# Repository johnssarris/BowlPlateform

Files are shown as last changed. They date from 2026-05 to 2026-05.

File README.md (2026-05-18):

# Dog Bowl Platform

Parametric, 3D-printable elevated dog bowl stand. Redesigned from scratch in OpenSCAD with three engineering priorities:

- **100% printed** — zero hardware, no bolts, no rubber feet, no glue
- **Tool-free** — snap-fit joints assemble and disassemble by hand in under 2 minutes
- **Portable** — 10 parts stack flat; toss in a bag

---

## Part List

| Part | Count | Unique shapes | File |
|---|---|---|---|
| Corner post | 4× | 1 | `openscad/parts/corner_post.scad` |
| Horizontal rail | 4× | 1 | `openscad/parts/horizontal_rail.scad` |
| Bowl cradle | 1–2× | 1 | `openscad/parts/bowl_cradle.scad` |

**3 unique shapes, 10 total pieces** (down from 32 in the original design).

---

## Structural Improvements vs Original

| Property | Original | Redesign | Gain |
|---|---|---|---|
| Frame cross-section | 10×10 mm solid | 20×20×3 mm hollow tube | 4× section modulus |
| Slenderness ratio | 47.6 : 1 | 23.8 : 1 | 2× column stability |
| Joint type | Flush / adhesive | Cantilever snap-tab | Hand-releasable, no glue |
| Foot contact area | 100 mm² | 962 mm² (ø35 pad) | 9.6× anti-tip stability |
| Part count | 32 | 10 | 69% reduction |
| Hardware needed | Adhesive | None | 100% printable |

---

## Quick Start

### 1. Open the master file

```
openscad/dog_bowl_platform.scad
```

Press **F5** (preview) to see the assembled stand.

### 2. Configure for your dog

Edit these variables at the top of `dog_bowl_platform.scad`:

```scad
bowl_diameter  = 200;   // outer diameter of your dog's bowl (mm)
num_bowls      = 2;     // 1 or 2 bowls
stand_height   = 200;   // floor to cradle surface (mm)
                         // rule of thumb: withers height × 0.45
```

Common `bowl_diameter` values:

| Bowl size | Diameter |
|---|---|
| Small (cat/small dog) | 140 mm |
| Medium dog | 180 mm |
| Large dog | 200–230 mm |
| Giant breed | 250 mm |

Common `stand_height` values:

| Dog size | Height |
|---|---|
| Small (≤10 kg) | 100 mm |
| Medium (10–25 kg) | 150–175 mm |
| Large (25–45 kg) | 200–250 mm |
| Giant (>45 kg) | 275–350 mm |

### 3. Export STL files

Run each part file individually to export one STL at a time:

```bash
# Using OpenSCAD CLI
openscad -o corner_post.stl    openscad/parts/corner_post.scad
openscad -o horizontal_rail.stl openscad/parts/horizontal_rail.scad
openscad -o bowl_cradle.stl    openscad/parts/bowl_cradle.scad
```

Or open each file in OpenSCAD, press **F6** (render), then **File → Export → Export as STL**.

> **Note:** The part files use `use <../dog_bowl_platform.scad>` to inherit parameters. Set your sizes in the master file before exporting.

### 4. Print settings

| Setting | Recommendation |
|---|---|
| Layer height | 0.2 mm |
| Infill | 30% (corner posts), 20% (rails and cradle) |
| Perimeters | 3 |
| Material | PLA or PETG |
| Supports | **None required** on any part |

**Print orientations:**

- **Corner post** — print vertically (Z-up). The foot pad is at the bottom of the print.
- **Horizontal rail** — print lying flat (longest axis along X). Snap tabs are at each end.
- **Bowl cradle** — print flat on bed, bowl openings facing up.

### 5. Tune fit tolerance

Default `snap_clearance = 0.25` works for most well-calibrated FDM printers.

- Too tight (tabs won't insert): increase to `0.30`
- Too loose (tabs rattle): decrease to `0.20`

Adjust in the master file and re-export only the affected parts.

---

## Assembly (tool-free, ~90 seconds)

1. Place 4 corner posts upright at the corners of your intended footprint, L-shape facing inward.
2. Slide the front rail's snap tabs into the slots on the two front posts — you'll hear/feel a click.
3. Slide the back rail into the two back posts.
4. Slide the left rail and right rail into their respective slots.
5. Drop the bowl cradle onto the top of the rail frame — the hook tabs on the cradle bottom engage the rail faces by gravity.
6. Place dog bowls.

**Disassembly:** Lift cradle straight up → squeeze each rail's snap tab cantilever inward and slide out → lift posts.

---

## Exploded View

Set `explode = 40` in the master file and press F5 to see all parts separated for verification.

---

## File Structure

```
openscad/
├── dog_bowl_platform.scad   ← Master file: all parameters + assembly
├── lib/
│   ├── frame.scad           ← Hollow chamfered tube module
│   └── joints.scad          ← Snap-tab and snap-slot modules
└── parts/
    ├── corner_post.scad     ← L-shaped post with integrated foot
    ├── horizontal_rail.scad ← Rail with snap tabs on both ends
    └── bowl_cradle.scad     ← Bowl support with hook tabs
STL/                         ← Original 32-piece design (reference)
Dog Bowl Plateform 2.step    ← Original OnShape assembly (reference)
```

---

## Design Notes

### Why hollow tube instead of solid?

A 20×20 mm hollow tube (3 mm wall) has **4× the section modulus** of the original 10×10 mm solid profile while using roughly the same material volume. Section modulus governs bending stiffness — the frame deflects far less under dog-bump loads.

### Why snap-fit instead of bolts?

Bolts require tools and mean hardware that can be lost. A properly designed cantilever snap-tab (3 mm wall, 15 mm arm) provides adequate retention under typical meal-time loading and releases with finger pressure. The cradle is gravity-retained and lifts off freely.

### Why a square footprint?

Making all 4 rails identical (one unique part instead of two) reduces print time and simplifies assembly. The square base footprint is derived directly from `bowl_diameter + 2 × bowl_rim`, so it scales correctly for any bowl size.

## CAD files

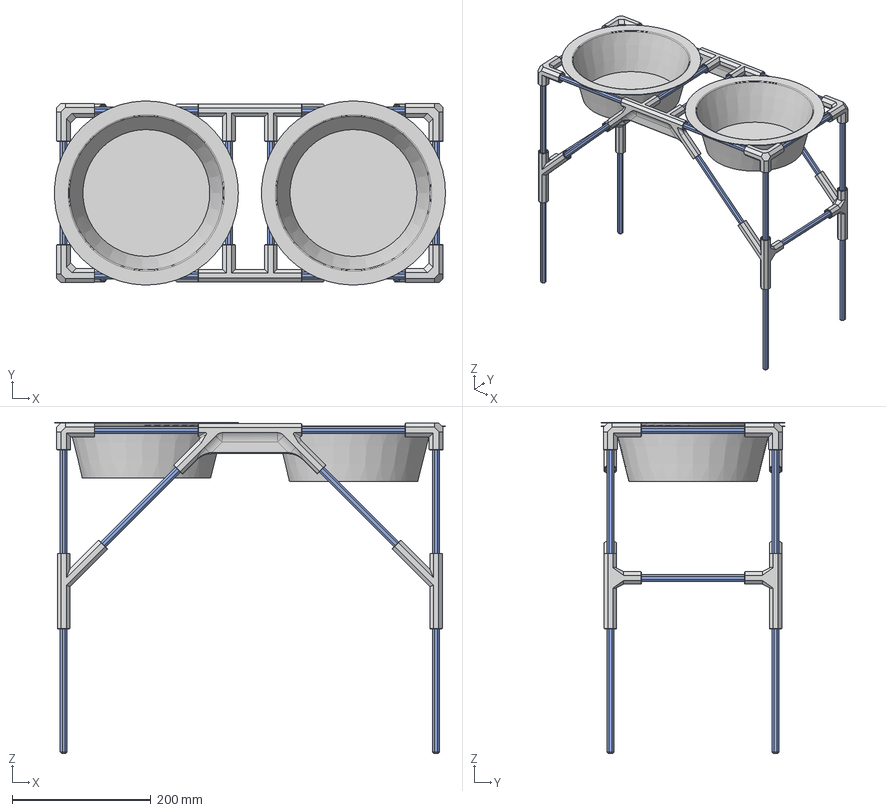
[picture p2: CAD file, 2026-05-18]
Dog Bowl Plateform.step
563.0 x 264.9 x 476.9 mm
Frame_Segment x 22
Center_Top x 2
Corner_Stabilizer_A x 2
Corner_Top x 4
Bowl x 2
Corner_Stabilizer_B x 2

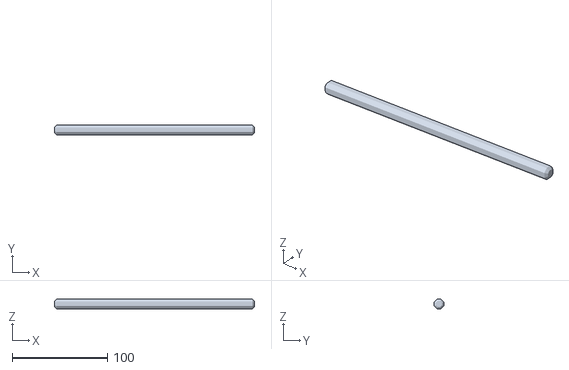
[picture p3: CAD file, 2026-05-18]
STL/Dog Bowl Plateform - Frame_Segment_20.stl
210.5 x 10.0 x 10.0

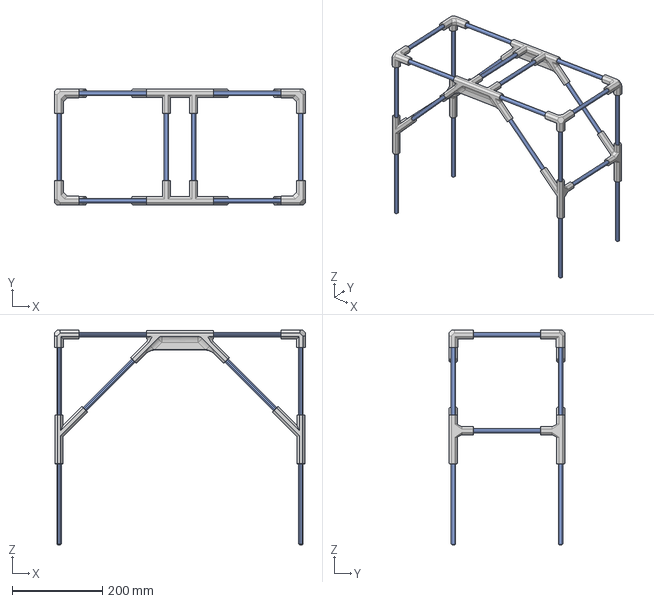
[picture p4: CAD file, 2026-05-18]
Dog Bowl Plateform 2.step
556.5 x 258.2 x 476.0 mm

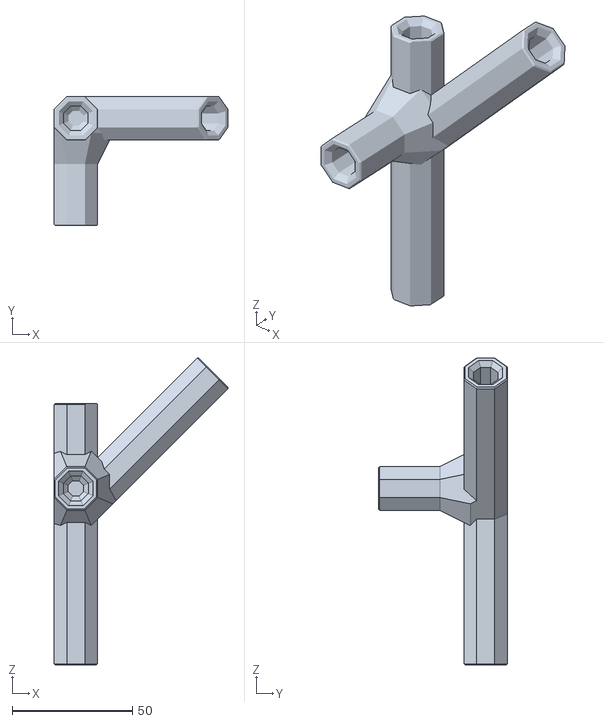
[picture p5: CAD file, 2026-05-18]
STL/Dog Bowl Plateform - Corner_Stabilizer_B_1.stl
72.3 x 53.6 x 127.5

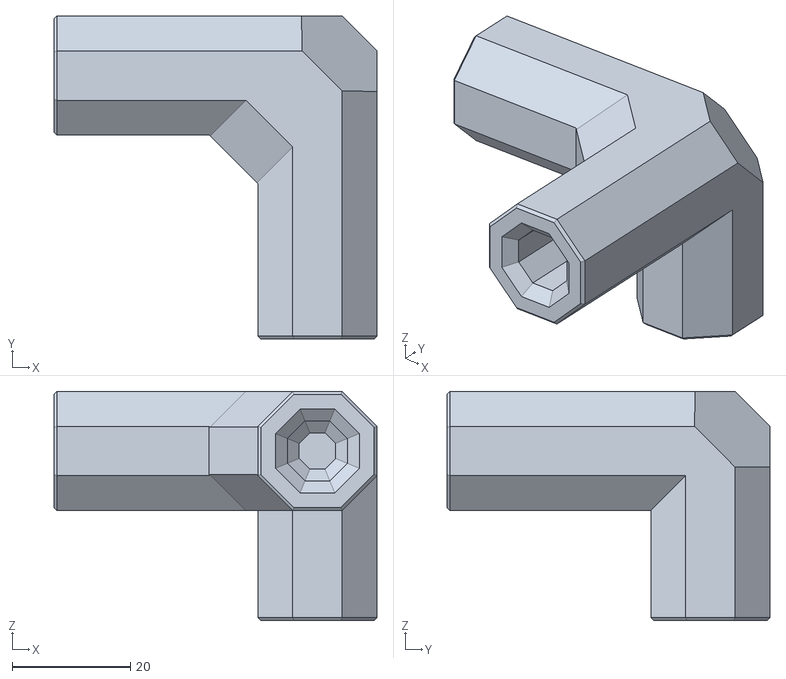
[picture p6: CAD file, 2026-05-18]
STL/Dog Bowl Plateform - Corner_Top_2.stl
54.6 x 54.6 x 38.8

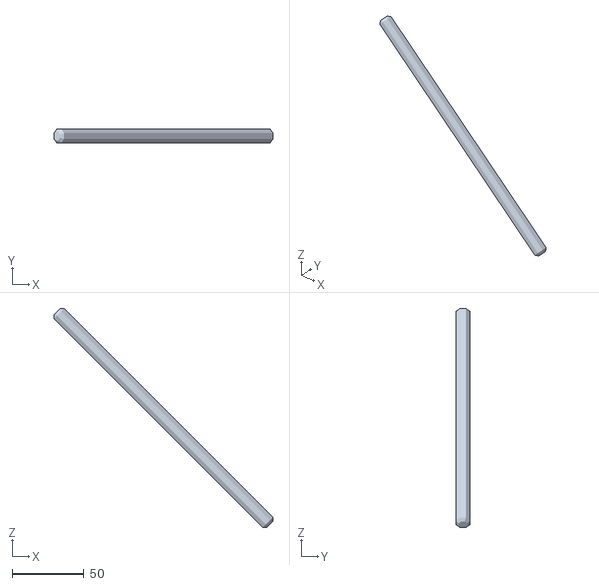
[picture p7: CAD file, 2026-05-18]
STL/Dog Bowl Plateform - Frame_Segment_2.stl
153.1 x 10.0 x 153.1

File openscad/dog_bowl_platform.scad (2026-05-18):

// ============================================================
// Dog Bowl Platform — Parametric OpenSCAD Redesign
// 100% printable · Tool-free snap assembly · Portable
//
// Part count: 10 pieces (3 unique types)
//   4× corner_post  |  4× horizontal_rail  |  1–2× bowl_cradle
//
// Assembly:
//   1. Place 4 posts at corners (any orientation — slots on all faces)
//   2. Snap front + back X-rails into post slots
//   3. Snap left + right Y-rails into post slots
//   4. Drop bowl cradle into the rail frame opening
// Disassembly: lift cradle → squeeze rail tabs → pull rails → lift posts
// ============================================================

// ── Bowl ─────────────────────────────────────────────────────────────
bowl_diameter = 200;   // mm  bowl outer rim diameter
                        //     small: 140  medium: 180  large: 200-230  giant: 250
num_bowls     = 2;     // 1 or 2
bowl_rim      = 25;    // mm  ledge around each bowl opening

// ── Stand ─────────────────────────────────────────────────────────────
stand_height  = 200;   // mm  floor to top of rail frame (cradle rests here)
                        //     small (~10kg): 100  medium: 150  large: 200-250

// ── Frame ─────────────────────────────────────────────────────────────
frame_w       = 20;    // mm  square tube outer dimension (was 10mm)
wall_t        = 3;     // mm  tube wall thickness
chamfer_r     = 2;     // mm  edge chamfer

// ── Snap-Fit Joint ────────────────────────────────────────────────────
tab_len       = 15;    // mm  snap tab length
snap_bump     = 1.2;   // mm  bump height — increase for stronger snap
snap_clearance= 0.25;  // mm  fit tolerance per side; try 0.30 on loose printers

// ── Foot ──────────────────────────────────────────────────────────────
foot_dia      = 35;    // mm  foot pad diameter at base of each post
foot_h        = 8;     // mm  foot pad height

// ── Render control ────────────────────────────────────────────────────
$fn           = 64;
explode       = 0;     // 0=assembled; set e.g. 30 for exploded view
print_mode    = false; // true=lay all parts flat to verify print sizing

// ── Derived (do not edit) ─────────────────────────────────────────────
tab_h    = frame_w * 0.55;   // tab height (Z) — matches slot Z extent
tab_w    = frame_w * 0.70;   // tab width (Y)
tab_taper = 1.5;              // lead-in taper length

// Cradle footprint: two bowls side by side along X, one bowl deep in Y
cradle_w = (num_bowls == 2)
    ? 2*bowl_diameter + 3*bowl_rim
    : bowl_diameter + 2*bowl_rim;
cradle_d = bowl_diameter + 2*bowl_rim;   // always single bowl depth

// Rail inner spans (body between post inner faces)
rail_len_x = cradle_w - snap_clearance*2;  // snug fit in X
rail_len_y = cradle_d - snap_clearance*2;  // snug fit in Y

// Platform outer footprint
base_x = cradle_w + 2*frame_w;
base_y = cradle_d + 2*frame_w;

// Rail Z: slot center at (height - tab_len - 2 + tab_h/2)
// Rail bottom Z = slot_center - frame_w/2 (rail is fw tall, centered on slot)
slot_zc     = stand_height - tab_len - 2 + tab_h/2;
rail_z_bot  = slot_zc - frame_w/2;
rail_top_z  = rail_z_bot + frame_w;       // cradle rests here

// Cradle clearance from rail inner span
cradle_cl   = snap_clearance * 2;

// ── Includes ─────────────────────────────────────────────────────────
use <parts/corner_post.scad>
use <parts/horizontal_rail.scad>
use <parts/bowl_cradle.scad>

// ─────────────────────────────────────────────────────────────────────
// Assembly
// ─────────────────────────────────────────────────────────────────────
module assembly() {
    ex = explode;

    // 4 corner posts, bottom-left corner at given XY
    // All posts are identical — slots on all 4 faces, no rotation needed.
    post_xy = [
        [0,            0           ],
        [base_x-frame_w, 0           ],
        [0,            base_y-frame_w],
        [base_x-frame_w, base_y-frame_w],
    ];
    for (p = post_xy) {
        ex_x = (p[0] == 0 ? -1 : 1) * ex * 0.4;
        ex_y = (p[1] == 0 ? -1 : 1) * ex * 0.4;
        translate([p[0]+ex_x, p[1]+ex_y, 0])
            corner_post(
                height=stand_height, frame_w=frame_w, wall_t=wall_t,
                chamfer=chamfer_r, tab_len=tab_len, snap_bump=snap_bump,
                snap_cl=snap_clearance, foot_dia=foot_dia, foot_h=foot_h
            );
    }

    // X-direction front rail
    // Tube: X=[fw, fw+rail_len_x], Y=[0,fw] (centered at fw/2), Z=[rail_z_bot, rail_z_bot+fw]
    // Left tab enters left post +X face; right tab enters right post -X face.
    translate([frame_w, frame_w/2, rail_z_bot - ex*0.1])
        horizontal_rail(len=rail_len_x, frame_w=frame_w, wall_t=wall_t,
                        chamfer=chamfer_r, tab_len=tab_len,
                        snap_bump=snap_bump, tab_taper=tab_taper);

    // X-direction back rail
    translate([frame_w, base_y-frame_w/2, rail_z_bot - ex*0.1])
        horizontal_rail(len=rail_len_x, frame_w=frame_w, wall_t=wall_t,
                        chamfer=chamfer_r, tab_len=tab_len,
                        snap_bump=snap_bump, tab_taper=tab_taper);

    // Y-direction left rail
    // rotate([0,0,90]) turns the X-rail into a Y-rail:
    //   rail runs Y=[fw, fw+rail_len_y], X=[0,fw] (centered at fw/2)
    translate([frame_w/2, frame_w, rail_z_bot - ex*0.1])
        rotate([0, 0, 90])
            horizontal_rail(len=rail_len_y, frame_w=frame_w, wall_t=wall_t,
                            chamfer=chamfer_r, tab_len=tab_len,
                            snap_bump=snap_bump, tab_taper=tab_taper);

    // Y-direction right rail
    translate([base_x-frame_w/2, frame_w, rail_z_bot - ex*0.1])
        rotate([0, 0, 90])
            horizontal_rail(len=rail_len_y, frame_w=frame_w, wall_t=wall_t,
                            chamfer=chamfer_r, tab_len=tab_len,
                            snap_bump=snap_bump, tab_taper=tab_taper);

    // Bowl cradle: drops into the rail frame, rests on rail top faces
    // Centred in the platform footprint
    cradle_x_ofs = (base_x - cradle_w + cradle_cl) / 2;
    cradle_y_ofs = (base_y - cradle_d + cradle_cl) / 2;
    translate([cradle_x_ofs, cradle_y_ofs, rail_top_z + ex*1.5])
        bowl_cradle(
            num_bowls=num_bowls,
            bowl_d=bowl_diameter,
            bowl_rim=bowl_rim,
            bowl_depth=60,
            cradle_w=cradle_w - cradle_cl,
            cradle_d=cradle_d - cradle_cl,
            wall_t=wall_t
        );
}

// ─────────────────────────────────────────────────────────────────────
// Print layout — all parts flat on a virtual sheet
// ─────────────────────────────────────────────────────────────────────
module print_layout() {
    sp = 15;  // spacing between parts

    // 4× corner posts (vertical — stand them up in slicer)
    for (i = [0:3])
        translate([i*(frame_w+sp), 0, 0])
            corner_post(height=stand_height, frame_w=frame_w, wall_t=wall_t,
                        chamfer=chamfer_r, tab_len=tab_len, snap_bump=snap_bump,
                        snap_cl=snap_clearance, foot_dia=foot_dia, foot_h=foot_h);

    // 2× X-rails (flat, longest axis along X)
    for (i = [0:1])
        translate([i*(rail_len_x+sp), base_x+sp, 0])
            horizontal_rail(len=rail_len_x, frame_w=frame_w, wall_t=wall_t,
                            chamfer=chamfer_r, tab_len=tab_len,
                            snap_bump=snap_bump, tab_taper=tab_taper);

    // 2× Y-rails
    for (i = [0:1])
        translate([i*(rail_len_y+sp), base_x+frame_w+sp*2, 0])
            horizontal_rail(len=rail_len_y, frame_w=frame_w, wall_t=wall_t,
                            chamfer=chamfer_r, tab_len=tab_len,
                            snap_bump=snap_bump, tab_taper=tab_taper);

    // Bowl cradle
    translate([0, base_x+frame_w*3+sp*3, 0])
        bowl_cradle(num_bowls=num_bowls, bowl_d=bowl_diameter, bowl_rim=bowl_rim,
                    bowl_depth=60, cradle_w=cradle_w-cradle_cl,
                    cradle_d=cradle_d-cradle_cl, wall_t=wall_t);
}

// ─────────────────────────────────────────────────────────────────────
if (print_mode) {
    print_layout();
} else {
    assembly();
}

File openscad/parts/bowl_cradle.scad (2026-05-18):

// Bowl cradle — drops into the rail frame opening, rests by gravity.
// Outer footprint matches rail inner span (set by caller via cradle_w, cradle_d).
// Prints flat on bed, bowl openings face up. No supports needed.
module bowl_cradle(
    num_bowls = 2,
    bowl_d    = 200,    // outer bowl rim diameter
    bowl_rim  = 25,     // ledge width around bowl opening
    bowl_depth = 60,    // depth of bowl pocket (bowl sinks this far)
    cradle_w  = 250,    // outer width  — set to rail_len_x - clearance
    cradle_d  = 250,    // outer depth  — set to rail_len_y - clearance
    wall_t    = 3,      // floor thickness under bowl
    drain_d   = 5       // drain hole diameter
) {
    cradle_h = bowl_depth + wall_t;

    // Bowl center positions along X
    function bowl_cx(i) =
        (num_bowls == 1) ? cradle_w / 2
        : (i == 0) ? bowl_d/2 + bowl_rim
                   : cradle_w - bowl_d/2 - bowl_rim;

    bowl_cy = cradle_d / 2;

    difference() {
        // Main body
        cube([cradle_w, cradle_d, cradle_h]);

        // Bowl pockets — open from the top face (Z=cradle_h), cut downward
        for (i = [0 : num_bowls-1]) {
            cx = bowl_cx(i);
            // Cylindrical pocket from top down to wall_t floor
            translate([cx, bowl_cy, wall_t])
                cylinder(h = bowl_depth + 0.1, d = bowl_d, $fn=64);
            // 45° chamfered entry lip (eases bowl in, printable without supports)
            translate([cx, bowl_cy, wall_t + bowl_depth - 3])
                cylinder(h=4, d1=bowl_d, d2=bowl_d+6, $fn=64);
            // Drain hole through floor
            translate([cx, bowl_cy, -0.1])
                cylinder(h=wall_t + 0.2, d=drain_d, $fn=32);
        }
    }
}

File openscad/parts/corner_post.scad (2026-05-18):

use <../lib/frame.scad>
use <../lib/joints.scad>

// Square corner post with integrated tapered foot pad.
// Body occupies X=[0,fw], Y=[0,fw], Z=[0,height].
// Slots on all 4 side faces so any corner rotation works.
// Prints vertically (Z-up). No supports needed.
module corner_post(
    height    = 200,
    frame_w   = 20,
    wall_t    = 3,
    chamfer   = 2,
    tab_len   = 15,
    snap_bump = 1.2,
    tab_taper = 1.5,
    snap_cl   = 0.25,
    foot_dia  = 35,
    foot_h    = 8
) {
    tab_h = frame_w * 0.55;
    tab_w = frame_w * 0.70;

    // Slot centered in Z at this height
    slot_zc = height - tab_len - 2 + tab_h/2;

    difference() {
        union() {
            // Post tube: X=[0,fw], Y=[0,fw], Z=[0,height]
            translate([frame_w/2, frame_w/2, 0])
                tube_profile(height, frame_w, wall_t, chamfer);

            // Tapered foot pad: wider base, tapers to post width
            // d1=foot_dia at Z=0, d2≈frame_w+2 at Z=foot_h (smooth join)
            translate([frame_w/2, frame_w/2, 0])
                cylinder(h=foot_h, d1=foot_dia, d2=frame_w+2, $fn=64);
        }

        // ── Slot on +X face (opens from X=fw inward in -X) ──────────
        translate([frame_w+0.1, frame_w/2, slot_zc])
            rotate([0, 180, 0])
                snap_slot(tab_len, tab_h, tab_w, snap_bump, tab_taper, snap_cl);

        // ── Slot on -X face (opens from X=0 inward in +X) ──────────
        translate([-0.1, frame_w/2, slot_zc])
            snap_slot(tab_len, tab_h, tab_w, snap_bump, tab_taper, snap_cl);

        // ── Slot on +Y face (opens from Y=fw inward in -Y) ──────────
        // rotate([0,0,-90]): local +X → world -Y
        translate([frame_w/2, frame_w+0.1, slot_zc])
            rotate([0, 0, -90])
                snap_slot(tab_len, tab_h, tab_w, snap_bump, tab_taper, snap_cl);

        // ── Slot on -Y face (opens from Y=0 inward in +Y) ──────────
        // rotate([0,0,90]): local +X → world +Y
        translate([frame_w/2, -0.1, slot_zc])
            rotate([0, 0, 90])
                snap_slot(tab_len, tab_h, tab_w, snap_bump, tab_taper, snap_cl);
    }
}

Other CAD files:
STL/Dog Bowl Plateform - Frame_Segment_3.stl
STL/Dog Bowl Plateform - Frame_Segment_16.stl
STL/Dog Bowl Plateform - Frame_Segment_21.stl
STL/Dog Bowl Plateform - Frame_Segment_6.stl
STL/Dog Bowl Plateform - Frame_Segment_14.stl
STL/Dog Bowl Plateform - Frame_Segment_4.stl
STL/Dog Bowl Plateform - Frame_Segment_9.stl
STL/Dog Bowl Plateform - Frame_Segment_10.stl
STL/Dog Bowl Plateform - Frame_Segment_11.stl
STL/Dog Bowl Plateform - Frame_Segment_13.stl
STL/Dog Bowl Plateform - Frame_Segment_7.stl
STL/Dog Bowl Plateform - Corner_Stabilizer_A_1.stl
openscad/parts/horizontal_rail.scad
STL/Dog Bowl Plateform - Center_Top.stl
STL/Dog Bowl Plateform - Center_Top_1.stl
STL/Dog Bowl Plateform - Corner_Stabilizer_A.stl
STL/Dog Bowl Plateform - Corner_Stabilizer_B.stl
STL/Dog Bowl Plateform - Corner_Top.stl
STL/Dog Bowl Plateform - Corner_Top_1.stl
STL/Dog Bowl Plateform - Corner_Top_3.stl
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

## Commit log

2026-05-18 Improve metadata in both STEP files
    - Fix FILE_NAME: replace Onshape hash ID with 'Dog_Bowl_Platform', add author/org
    - Fix typo: 'Dog Bowl Plateform' → 'Dog Bowl Platform' throughout v1 (PRODUCT, REPRESENTATION_CONTEXT, SHAPE_REPRESENTATION)
    - Add meaningful descriptions to all PRODUCT entities (7 in v1, 32 in v2)
    - Classify PRODUCT_RELATED_PRODUCT_CATEGORY as 'assembly'/'part' with descriptions
    - Set PRODUCT_DEFINITION_FORMATION version to '1' / 'Initial design release'
    - Set PRODUCT_CATEGORY to 'mechanical' / 'Mechanical design category'
    No geometry or coordinate data was modified.
    https://claude.ai/code/session_01S7NPvw4593SuNryic58nbE
    [Dog Bowl Plateform 2.step, Dog Bowl Plateform.step]
2026-05-18 Move all STL files into STL/ subfolder
    Organizes the 32 individual component STL files into a dedicated
    STL/ directory, keeping the repo root clean with just the STEP
    assembly files and README.
    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
    [Dog Bowl Plateform - Center_Top.stl, Dog Bowl Plateform - Center_Top_1.stl, Dog Bowl Plateform - Corner_Stabilizer_A.stl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]
2026-05-18 Redesign dog bowl platform as parametric OpenSCAD project
    Replaces the 32-piece OnShape export with a clean parametric design:
    - 10 total pieces (3 unique types): 4× corner post, 4× horizontal rail,
    1–2× bowl cradle
    - 100% printable — zero hardware, no bolts, no rubber feet, no adhesive
    - Tool-free assembly: cantilever snap-tab joints click by hand and
    release by squeezing; cradle rests by gravity in the rail frame
    - Portable: disassembles flat in under 2 minutes
    Engineering improvements over original:
    - Frame cross-section 10×10 solid → 20×20×3 hollow tube (4× section modulus)
    - Slenderness ratio 47.6:1 → 23.8:1 (2× column stability)
    - Slots on all 4 post faces — iden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
    [bowl_cradle.scad, corner_post.scad, dog_bowl_platform.scad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]
2026-05-18 Add PWA SCAD viewer — render and tweak the stand from iPhone
    - index.html: single-page app shell with mobile-first layout, safe-area
    insets, importmap for Three.js, and parameters slide-up drawer
    - manifest.json + sw.js: installable PWA with cache-first offline support
    - js/scad-worker.js: Web Worker that loads openscad-wasm from CDN and
    compiles SCAD to STL; supports -D parameter overrides for the assembly
    view and generates self-contained wrapper SCAD for individual parts
    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
2026-05-18 Show render errors and full logs in-app instead of console-only
    Previously errors were logged to console.error (invisible on iPhone).
    Now:
    - showError() displays a brief summary in the status overlay and opens
    a red debug panel with the full error text + all captured log lines
    - "Copy to clipboard" button lets the user share the error details
    - Worker now logs each init step (CDN URL, found globals, factory name,
    callMain args) so the trace shows exactly where a failure occurred
    https://claude.ai/code/session_01QERZhwq5q2pEQUiutY5V9J
2026-05-18 Fix iOS Safari CORS, add version display and update notification
    CORS fix: iOS Safari refuses cross-origin importScripts() even with
    CORS headers. Workaround: fetch() the openscad.js text, wrap it in a
    same-origin Blob URL, then importScripts(blobUrl). fetch() honours CORS
    headers correctly; locateFile still redirects the WASM binary to CDN.
    Version display: version.json served network-first (never stale) so the
    header always shows the currently deployed version. Bump "version" in
    version.json on each push to confirm a new build is active.
    Update notification: service worker no longer auto-skips waiting. When a
    new SW installs it sits in waiting state; app.js detects reg.waiting /
    updatefo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
2026-05-18 Switch to module worker with dynamic import() for openscad-wasm
    openscad-wasm@0.0.4 is an ES module (uses import.meta internally).
    The blob+importScripts workaround failed because importScripts() runs
    code as a classic script where import.meta is illegal.
    Fix: create the worker with {type:'module'} and load openscad.js via
    dynamic import(). In a module worker, import() of a cross-origin ES
    module is fully supported. import.meta.url inside openscad.js resolves
    to the CDN URL so the WASM binary is found automatically.
    Version bump: 1.3
    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
